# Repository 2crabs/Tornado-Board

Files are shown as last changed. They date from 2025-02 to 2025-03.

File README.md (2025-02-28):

<p align="center">
    <picture>
      <source media="(prefers-color-scheme: dark)" srcset="Images/logo-darkTheme.png">
      <source media="(prefers-color-scheme: light)" srcset="Images/logo-lightTheme.png">
      
    </picture>
</p>

---

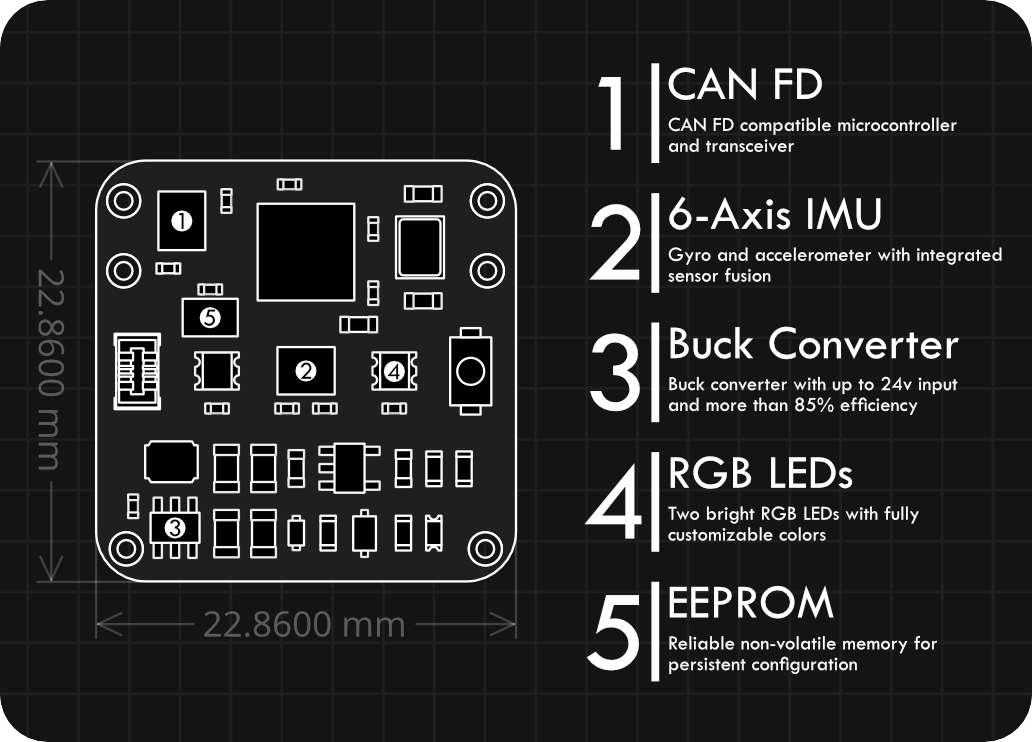
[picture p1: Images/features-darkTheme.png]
PCB features

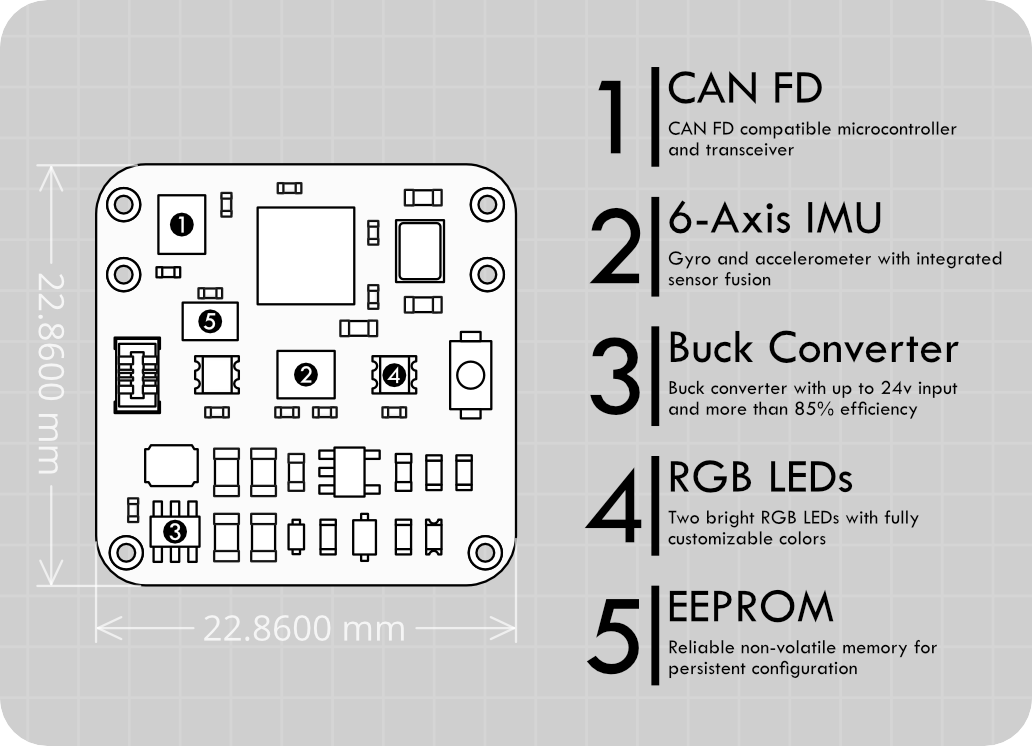
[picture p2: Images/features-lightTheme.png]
PCB features

Tornado is a fully open-source IMU board built for FRC

## Block Diagram
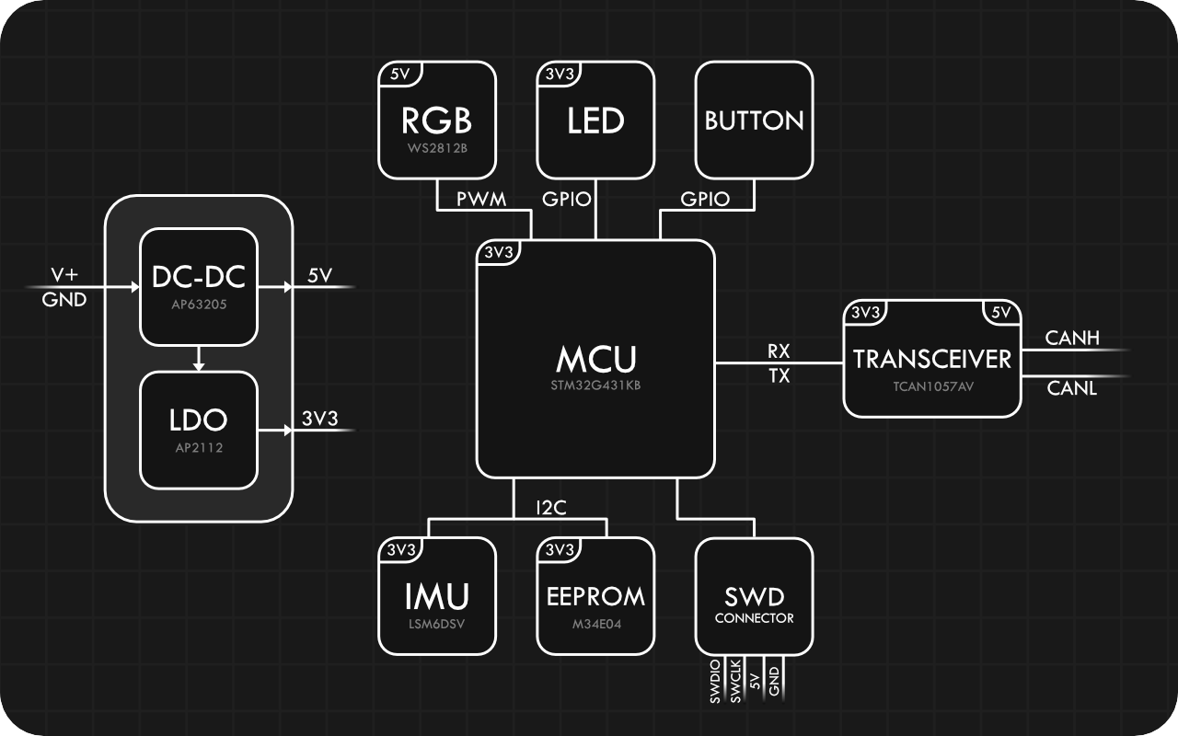
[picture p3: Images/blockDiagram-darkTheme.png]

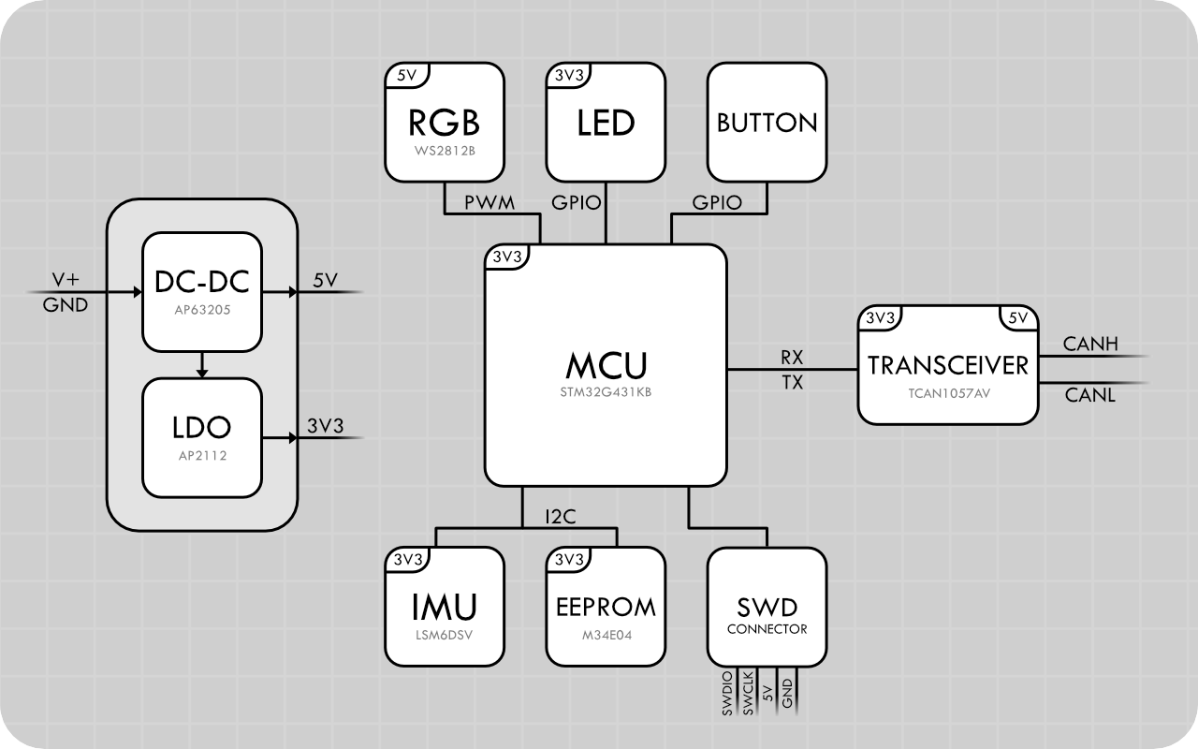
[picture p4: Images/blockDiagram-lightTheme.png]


## Resources
* [Schematic](Images/Schematic.pdf)

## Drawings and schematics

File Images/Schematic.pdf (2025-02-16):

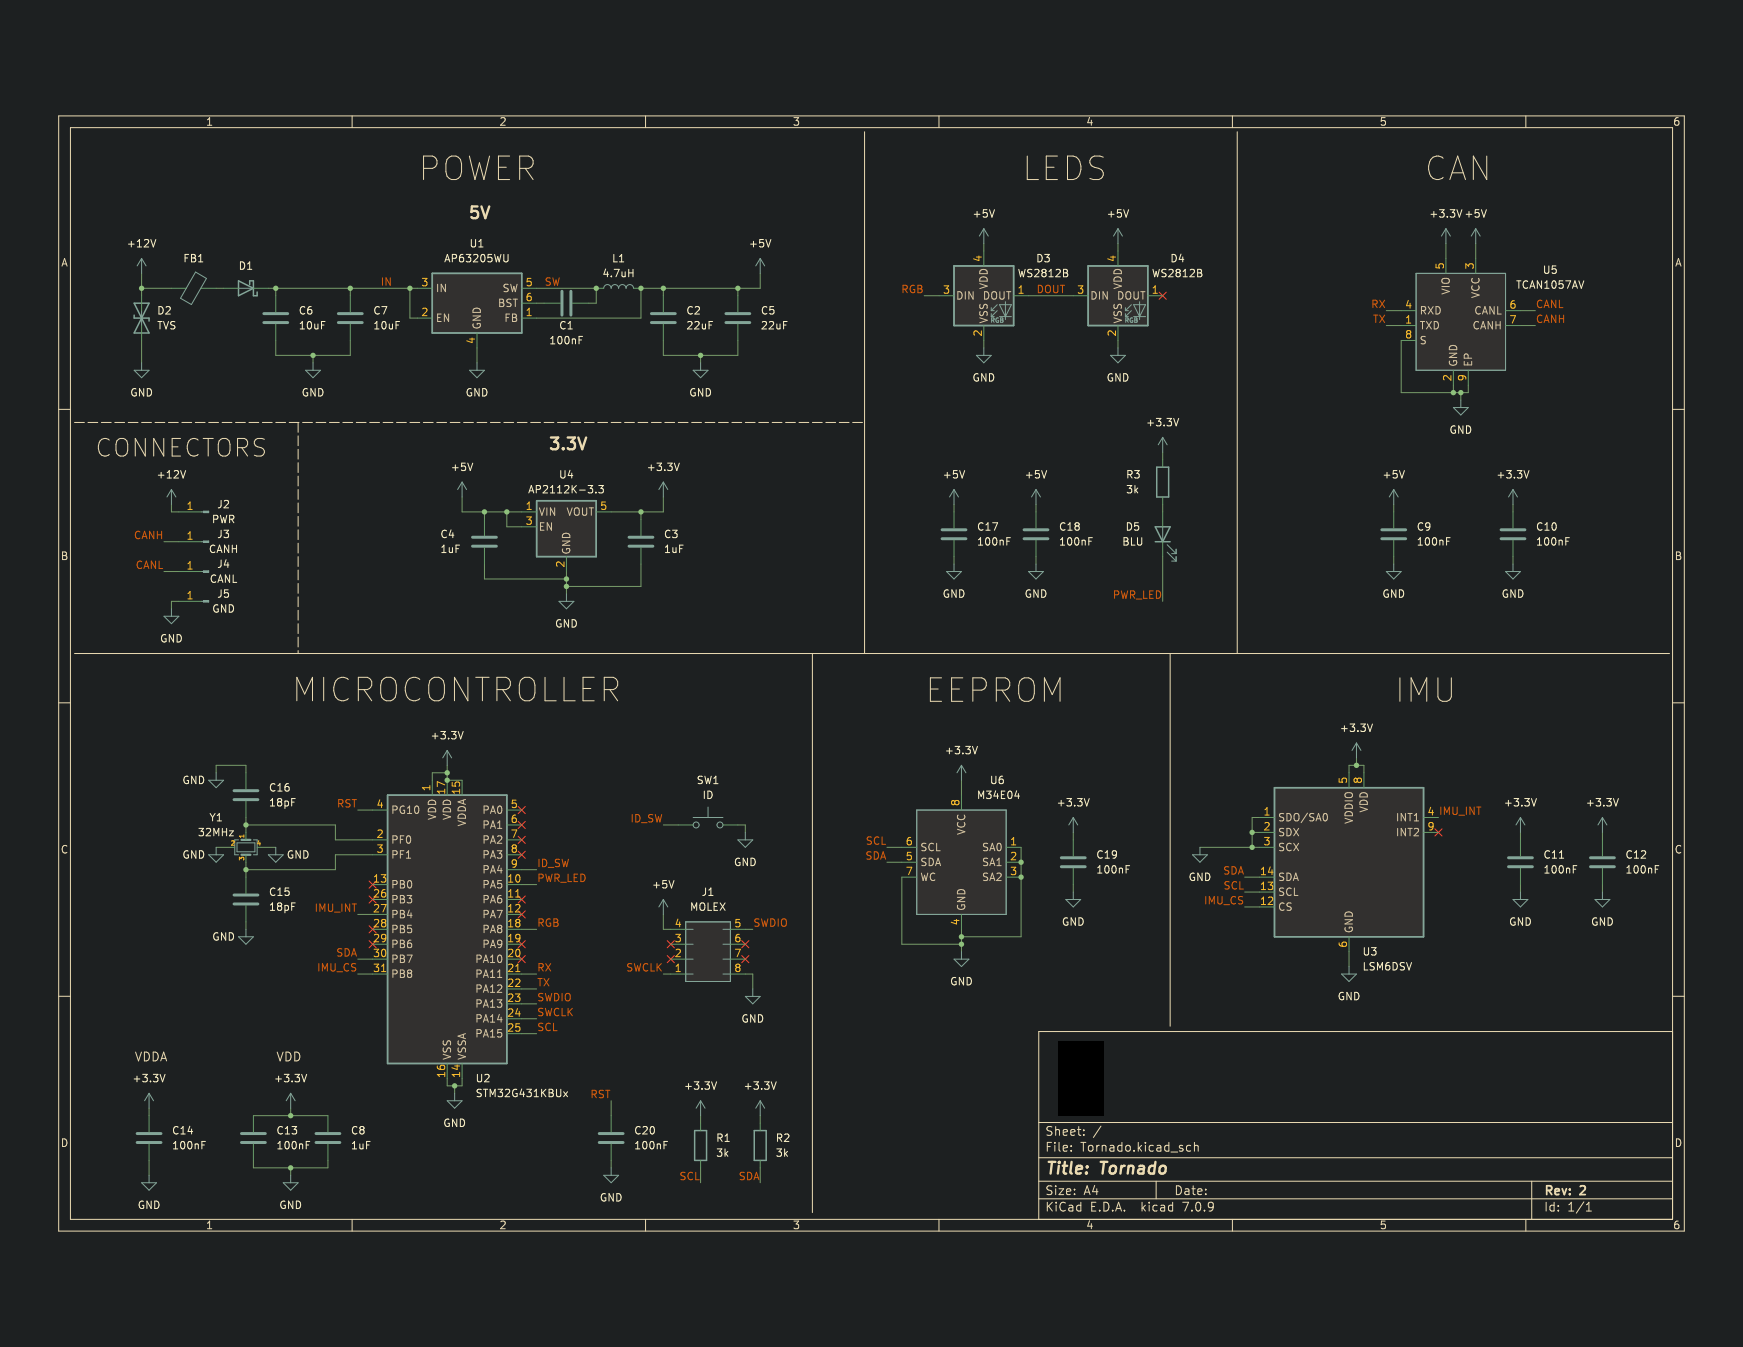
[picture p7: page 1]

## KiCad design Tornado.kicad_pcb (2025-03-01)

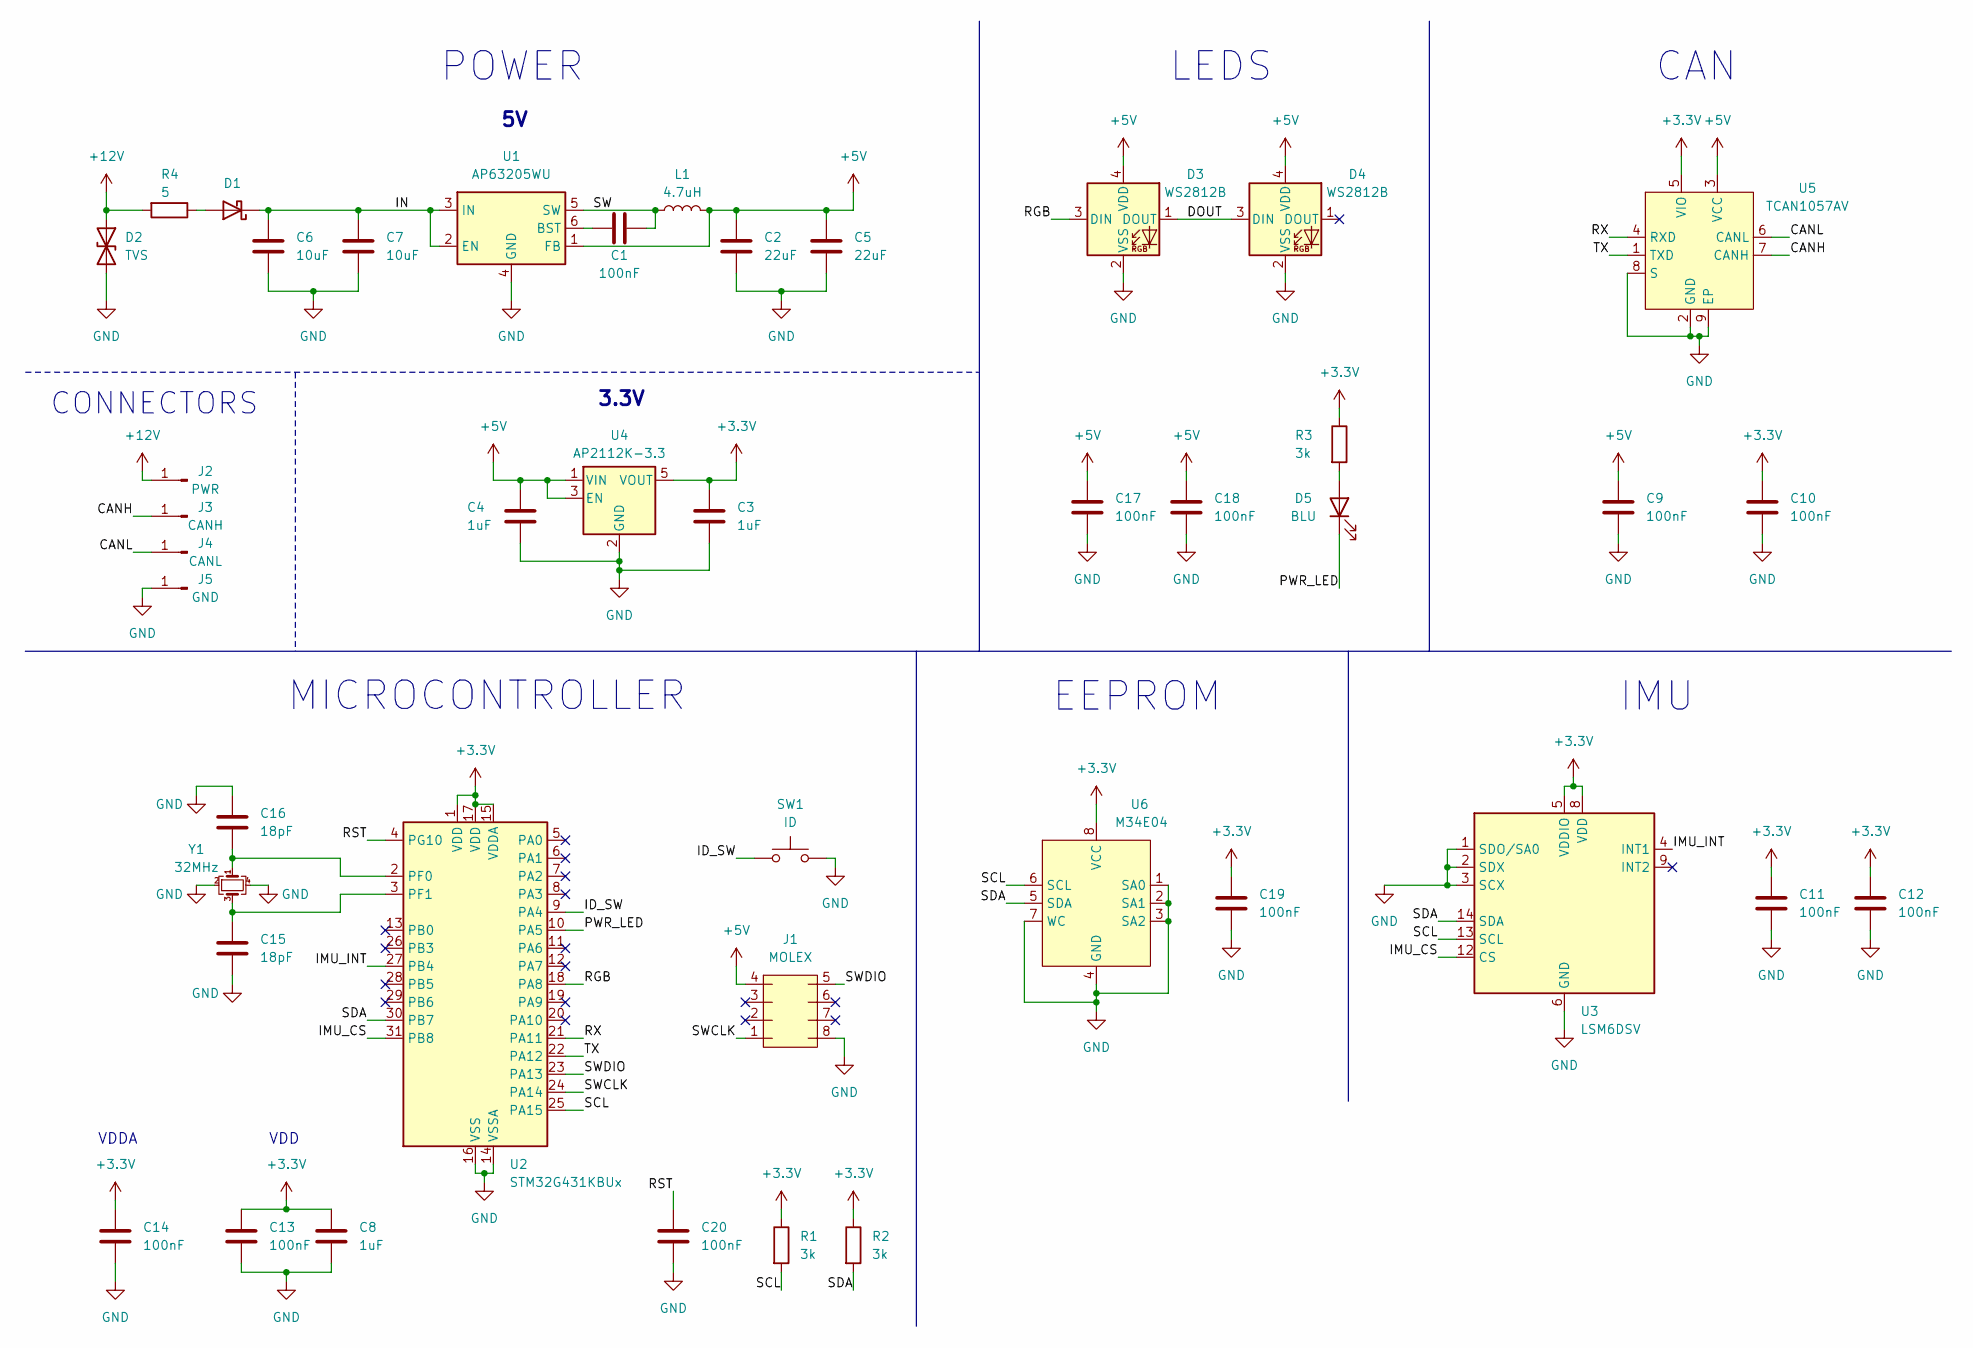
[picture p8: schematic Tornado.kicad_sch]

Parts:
C1, C9, C10, C11, C12, C13, C14, C17, C18, C19, C20: 100nF; C_0402_1005Metric
C2, C5: 22uF; C_0805_2012Metric
C3, C4, C8: 1uF; C_0603_1608Metric
C6, C7: 10uF; C_0805_2012Metric
C15, C16: 18pF; C_0603_1608Metric
D1: D_Schottky; D_SOD-523
D2: TVS; D_SOD-323
D3, D4: WS2812B; WS2812B-2020
D5: BLU; LED_0603_1608Metric
J1: MOLEX; 5050040812-MOLEX
J2: PWR; Wire_Hole
J3: CANH; Wire_Hole
J4: CANL; Wire_Hole
J5: GND; Wire_Hole
L1: 4.7uH; L_1008_2520Metric
R1, R2, R3: 3k; R_0603_1608Metric
R4: 5; R_0603_1608Metric
SW1: ID; TC029
U1: AP63205WU; TSOT-23-6
U2: STM32G431KBUx; QFN-32-1EP_5x5mm_P0.5mm_EP3.45x3.45mm
U3: LSM6DSV; LGA-14_3x2.5mm_P0.5mm_LayoutBorder3x4y
U4: AP2112K-3.3; SOT-23-5
U5: TCAN1057AV
U6: M34E04; 8-UFDFPN
Y1: 32MHz; Crystal_SMD_3225-4Pin_3.2x2.5mm

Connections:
+3.3V: C3.1, C8.1, C10.1, C11.1, C12.1, C13.1, C14.1, C19.1, R1.1, R2.1, R3.1, U2.1 (VDD), U2.15 (VDDA), U2.17 (VDD), U3.5 (VDDIO), U3.8 (VDD), U4.5 (VOUT), U5.5 (VIO), U6.8 (VCC)
+5V: C2.1, C4.1, C5.1, C9.1, C17.1, C18.1, D3.4 (VDD), D4.4 (VDD), J1.4, L1.2, U1.1 (FB), U4.1 (VIN), U4.3 (EN), U5.3 (VCC)
+12V: D2.1 (A1), J2.1, R4.2
/CANH: J3.1, U5.7 (CANH); also elsewhere on the board
/CANL: J4.1, U5.6 (CANL); also elsewhere on the board
/DOUT: D3.1 (DOUT), D4.3 (DIN)
/ID_SW: SW1.1, U2.9 (PA4)
/IMU_CS: U2.31 (PB8), U3.12 (CS)
/IMU_INT: U2.27 (PB4), U3.4 (INT1)
/IN: C6.2, C7.1, D1.1 (K), U1.2 (EN), U1.3 (IN)
/PWR_LED: D5.1 (K), U2.10 (PA5)
/RGB: D3.3 (DIN), U2.18 (PA8)
/RST: C20.1, U2.4 (PG10)
/RX: U2.21 (PA11), U5.4 (RXD)
/SCL: R1.2, U2.25 (PA15), U3.13 (SCL), U6.6 (SCL)
/SDA: R2.2, U2.30 (PB7), U3.14 (SDA), U6.5 (SDA)
/SW: C1.1, L1.1, U1.5 (SW)
/SWCLK: J1.1, U2.24 (PA14)
/SWDIO: J1.5, U2.23 (PA13)
/TX: U2.22 (PA12), U5.1 (TXD)
GND: C2.2, C3.2, C4.2, C5.2, C6.1, C7.2, C8.2, C9.2, C10.2, C11.2, C12.2, C13.2, C14.2, C15.2, C16.1, C17.2, C18.2, C19.2, C20.2, D2.2 (A2), D3.2 (VSS), D4.2 (VSS), J1.8, J5.1, SW1.2, U1.4 (GND), U2.14 (VSSA), U2.16 (VSS), U2.32 (VSS), U2.33 (VSS), U3.1 (SDO/SA0), U3.2 (SDX), U3.3 (SCX), U3.6 (GND), U3.7 (GND), U4.2 (GND), U5.2 (GND), U5.8 (S), U5.9 (EP), U6.1 (SA0), U6.2 (SA1), U6.3 (SA2), U6.4 (GND), U6.7 (WC), Y1.2, Y1.4
unnamed: D1.2 (A), R4.1
unnamed: D5.2 (A), R3.2
unnamed: C1.2, U1.6 (BST)
unnamed: C16.2, U2.2 (PF0), Y1.1
unnamed: C15.1, U2.3 (PF1), Y1.3

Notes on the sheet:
CONNECTORS
IMU
VDD
LEDS
MICROCONTROLLER
3.3V
POWER
EEPROM
CAN
VDDA

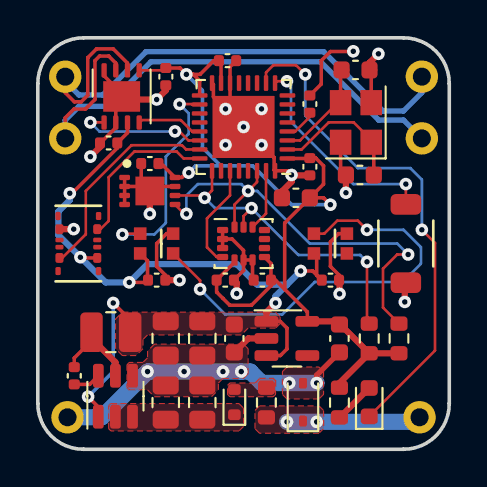
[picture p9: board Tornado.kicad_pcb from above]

Board: 4 copper layers, 22.9 x 22.9 mm, 45 parts (0 on the bottom side), 26 nets.

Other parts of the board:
J3#2: CANH; Wire_Hole
J4#2: CANL; Wire_Hole

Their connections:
/CANH: J3#2.1; also elsewhere on the board
/CANL: J4#2.1; also elsewhere on the board

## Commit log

2024-07-23 Added project files
    [Tornado.kicad_pcb, Tornado.kicad_sch]
2024-08-27 Added graphics
    [Tornado.kicad_pcb]
2024-09-29 Hid unused text
    [Tornado.kicad_pcb]
2024-09-29 Fixed Copper Pour
    [Tornado.kicad_pcb]
2024-09-29 Fixed silkscreen
    [Tornado.kicad_pcb]
2024-10-03 Changed ESD diode
    [Tornado.kicad_pcb, Tornado.kicad_sch]
2024-10-04 Replaced pads with holes
    [Tornado.kicad_pcb, Tornado.kicad_sch]
2024-11-05 Added Silkscreen
    [Tornado.kicad_pcb, Tornado.kicad_sch]
2024-11-05 Added Ferrite Bead
    [Tornado.kicad_pcb, Tornado.kicad_sch]
2025-02-16 Updated RGB Symbol
    [Tornado.kicad_sch]
2025-03-01 Added resistor to filter
    [Tornado.kicad_pcb, Tornado.kicad_sch]
